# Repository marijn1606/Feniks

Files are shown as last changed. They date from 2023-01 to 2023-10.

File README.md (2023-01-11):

# Feniks

Relatively cheap wifi enabled 4 channel BBQ thermometer based on a ESP32-C3.

The system is powered by an 18650 li-ion battery, and has integrated battery charge and protection circuitry.

The temperature probe data is displayed on a small I2C OLED screen as well as a webserver hosted on the ESP.

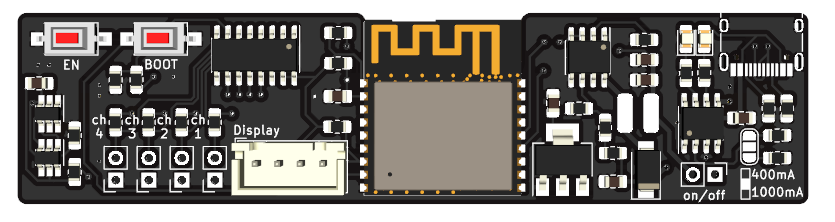
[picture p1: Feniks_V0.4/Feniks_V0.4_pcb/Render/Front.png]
Front

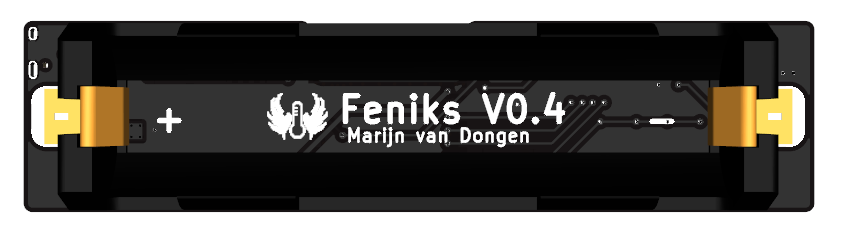
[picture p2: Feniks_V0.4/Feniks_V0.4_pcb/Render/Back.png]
Back


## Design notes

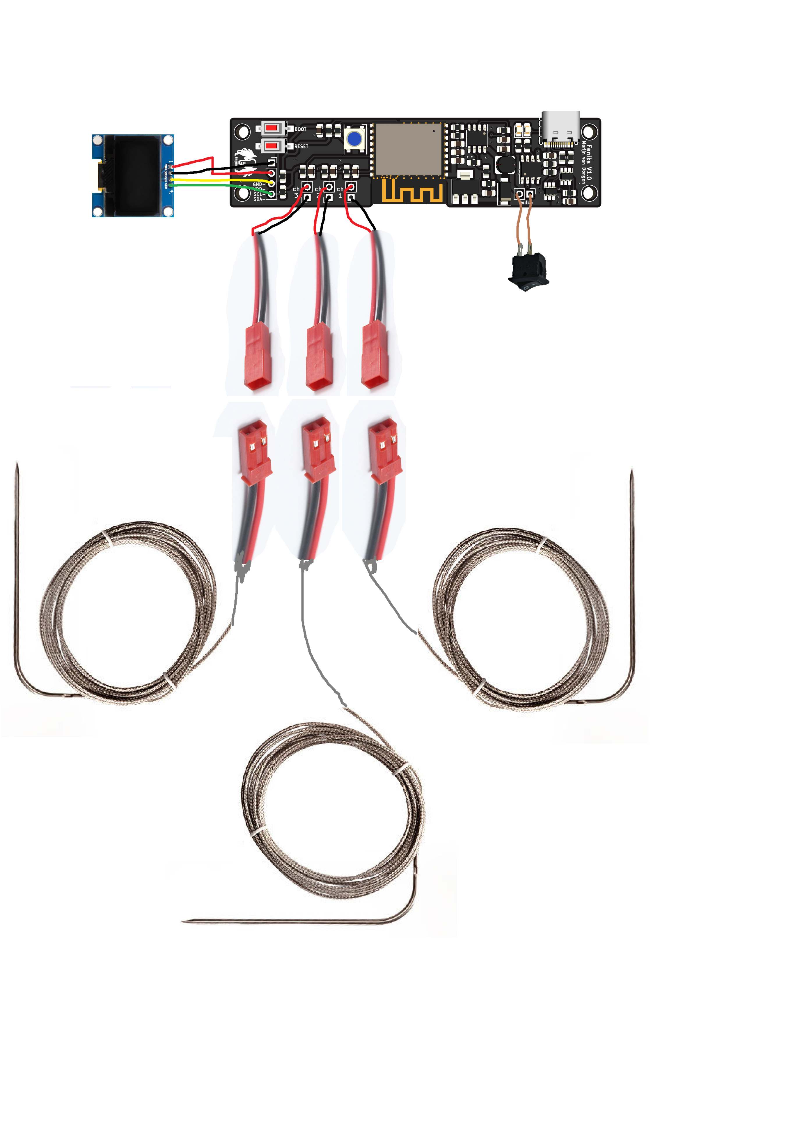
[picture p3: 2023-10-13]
Feniks_V0.5/Feniks_V0.5_pcb/Render/cable_sketch.png

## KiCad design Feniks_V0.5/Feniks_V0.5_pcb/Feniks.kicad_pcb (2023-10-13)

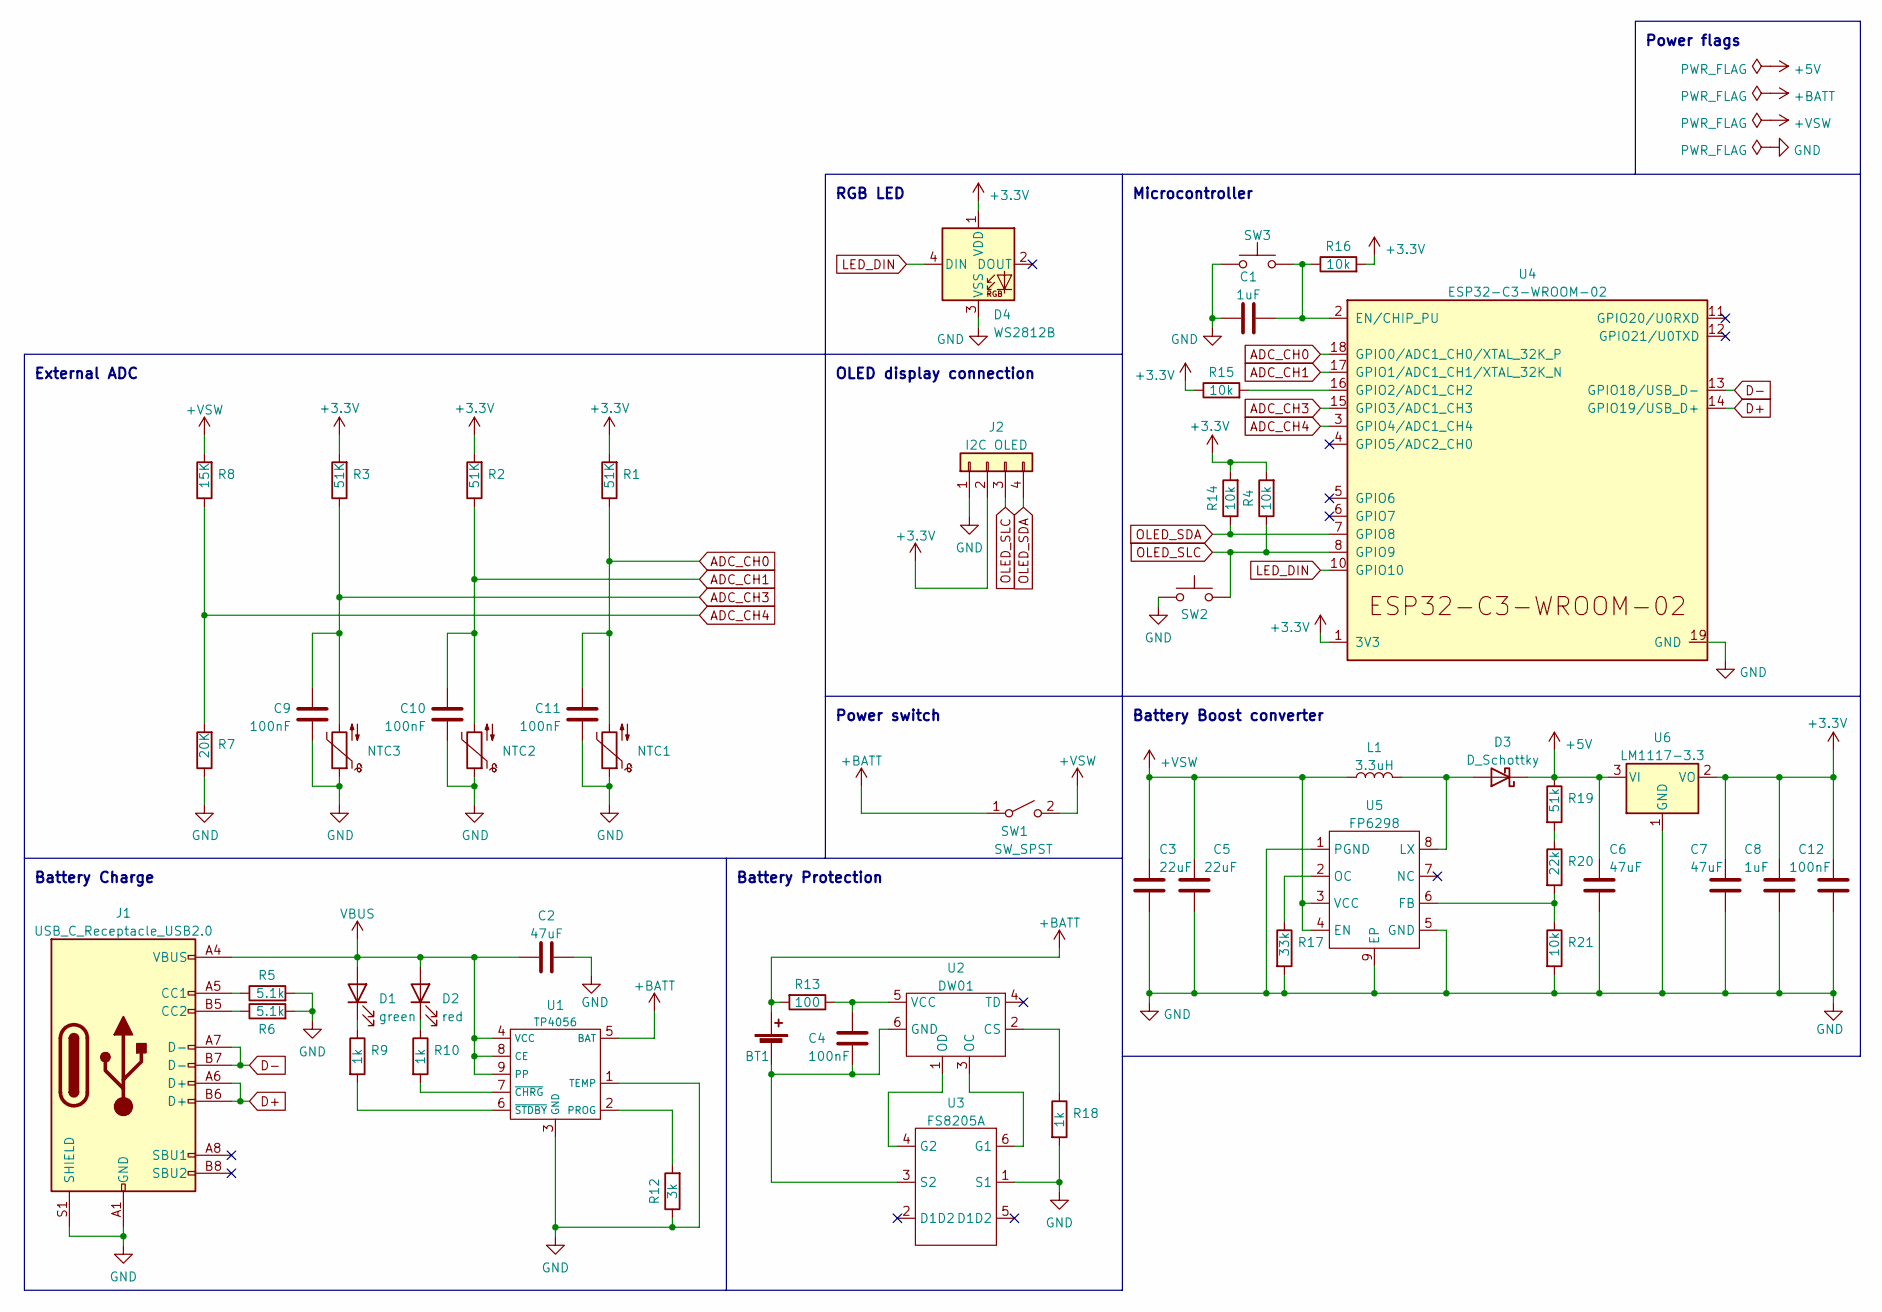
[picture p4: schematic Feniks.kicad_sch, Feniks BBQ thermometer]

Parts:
BT1: Battery_Cell; 18650SMT holder
C1, C8: 1uF; C_0805_2012Metric_Pad1.18x1.45mm_HandSolder
C2, C6, C7: 47uF; C_0805_2012Metric_Pad1.18x1.45mm_HandSolder
C3, C5: 22uF; C_0805_2012Metric_Pad1.18x1.45mm_HandSolder
C4, C9, C10, C11, C12: 100nF; C_0805_2012Metric_Pad1.18x1.45mm_HandSolder
D1: green; LED_0805_2012Metric_Pad1.15x1.40mm_HandSolder
D2: red; LED_0805_2012Metric_Pad1.15x1.40mm_HandSolder
D3: D_Schottky; D_SMA
D4: WS2812B; LED_WS2812B_PLCC4_5.0x5.0mm_P3.2mm
J1: USB_C_Receptacle_USB2.0; USB_C_Receptacle_HRO_TYPE-C-31-M-12
J2: I2C OLED; PinSocket_1x04_P2.54mm_Vertical
L1: 3.3uH; CD43
NTC1, NTC2, NTC3: Thermistor_NTC; PinSocket_1x02_P2.54mm_Vertical
R1, R2, R3: 51K; R_0805_2012Metric_Pad1.20x1.40mm_HandSolder
R4, R14, R15, R16, R21: 10k; R_0805_2012Metric_Pad1.20x1.40mm_HandSolder
R5, R6: 5.1k; R_0805_2012Metric_Pad1.20x1.40mm_HandSolder
R7: 20K; R_0805_2012Metric_Pad1.20x1.40mm_HandSolder
R8: 15K; R_0805_2012Metric_Pad1.20x1.40mm_HandSolder
R9, R10, R18: 1k; R_0805_2012Metric_Pad1.20x1.40mm_HandSolder
R12: 3k; R_0805_2012Metric_Pad1.20x1.40mm_HandSolder
R13: 100; R_0805_2012Metric_Pad1.20x1.40mm_HandSolder
R17: 33k; R_0805_2012Metric_Pad1.20x1.40mm_HandSolder
R19: 51k; R_0805_2012Metric_Pad1.20x1.40mm_HandSolder
R20: 22k; R_0805_2012Metric_Pad1.20x1.40mm_HandSolder
SW1: SW_SPST; PinHeader_1x02_P2.54mm_Vertical
SW2, SW3: SW_Push; SW_SPST_CK_RS282G05A3
U1: TP4056; SOIC-8-1EP_3.9x4.9mm_P1.27mm_EP2.29x3mm_ThermalVias
U2: DW01; SOT-23-6_Handsoldering
U3: FS8205A; SOT-23-6_Handsoldering
U4: ESP32-C3-WROOM-02
U5: FP6298; SOIC-8-1EP_3.9x4.9mm_P1.27mm_EP2.29x3mm_ThermalVias
U6: LM1117-3.3; SOT-223-3_TabPin2

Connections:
+3.3V: C7.1, C8.1, C12.1, D4.1 (VDD), J2.2, R1.2, R2.2, R3.2, R4.2, R14.2, R15.1, R16.2, U4.1 (3V3), U6.2 (VO)
+5V: C6.1, D3.1 (K), R19.1, U6.3 (VI)
+BATT: BT1.1 (+), R13.2, SW1.1 (A), U1.5 (BAT)
+VSW: C3.1, C5.1, L1.1, R8.2, SW1.2 (B), U5.3 (VCC), U5.4 (EN)
ADC_CH0: C11.2, NTC1.2, R1.1, U4.18 (GPIO0/ADC1_CH0/XTAL_32K_P)
ADC_CH1: C10.2, NTC2.2, R2.1, U4.17 (GPIO1/ADC1_CH1/XTAL_32K_N)
ADC_CH3: C9.2, NTC3.2, R3.1, U4.15 (GPIO3/ADC1_CH3)
ADC_CH4: R7.2, R8.1, U4.3 (GPIO4/ADC1_CH4)
D+: J1.A6 (D+), J1.B6 (D+), U4.14 (GPIO19/USB_D+)
D-: J1.A7 (D-), J1.B7 (D-), U4.13 (GPIO18/USB_D-)
GND: C1.1, C2.2, C3.2, C5.2, C6.2, C7.2, C8.2, C9.1, C10.1, C11.1, C12.2, D4.3 (VSS), J1.A1 (GND), J1.A12 (GND), J1.B1 (GND), J1.B12 (GND), J1.S1 (SHIELD), J2.1, NTC1.1, NTC2.1, NTC3.1, R5.2, R6.2, R7.1, R12.1, R17.2, R18.2, R21.2, SW2.1, SW3.1, U1.1 (TEMP), U1.3 (GND), U3.1 (S1), U4.9 (GND), U4.19 (GND), U5.1 (PGND), U5.5 (GND), U5.9 (EP), U6.1 (GND)
LED_DIN: D4.4 (DIN), U4.10 (GPIO10)
unnamed: BT1.2 (-), C4.1, U2.6 (GND), U3.3 (S2)
unnamed: C1.2, R16.1, SW3.2, U4.2 (EN/CHIP_PU)
unnamed: C4.2, R13.1, U2.5 (VCC)
unnamed: D1.1 (K), R9.1
unnamed: D2.1 (K), R10.1
unnamed: D3.2 (A), L1.2, U5.8 (LX)
unnamed: J1.A5 (CC1), R5.1
unnamed: J1.B5 (CC2), R6.1
unnamed: R9.2, U1.6 (~STDBY)
unnamed: R10.2, U1.7 (~CHRG)
unnamed: R12.2, U1.2 (PROG)
unnamed: R15.2, U4.16 (GPIO2/ADC1_CH2)
unnamed: R17.1, U5.2 (OC)
unnamed: R18.1, U2.2 (CS)
unnamed: R19.2, R20.1
unnamed: R20.2, R21.1, U5.6 (FB)
unnamed: U2.1 (OD), U3.4 (G2)
unnamed: U2.3 (OC), U3.6 (G1)
OLED_SDA: J2.4, R14.1, U4.7 (GPIO8)
OLED_SLC: J2.3, R4.1, SW2.2, U4.8 (GPIO9)
VBUS: C2.1, D1.2 (A), D2.2 (A), J1.A4 (VBUS), J1.A9 (VBUS), J1.B4 (VBUS), J1.B9 (VBUS), U1.4 (VCC), U1.8 (CE), U1.9 (PP)

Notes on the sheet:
Microcontroller
Power flags
Battery Protection
Battery Boost converter
OLED display connection
RGB LED
Battery Charge
External ADC
Power switch

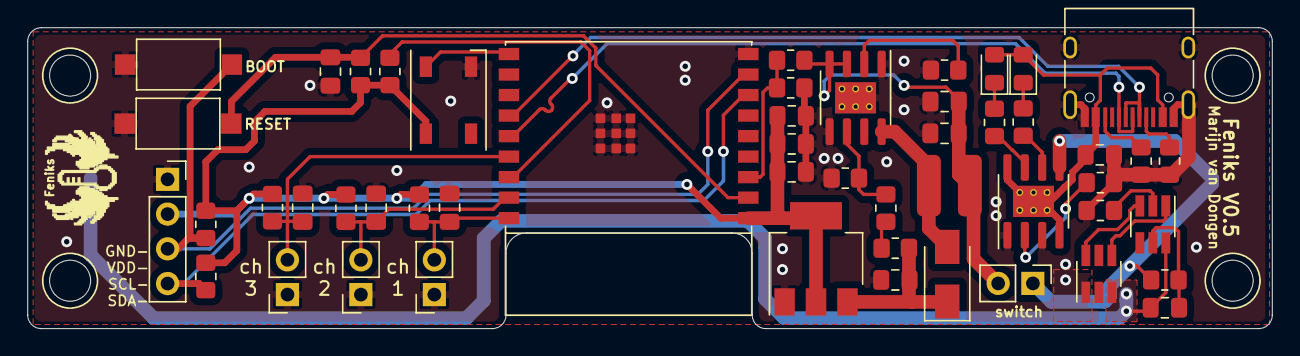
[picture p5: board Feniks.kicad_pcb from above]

Board: 2 copper layers, 91.0 x 22.0 mm, 52 parts (1 on the bottom side), 33 nets.

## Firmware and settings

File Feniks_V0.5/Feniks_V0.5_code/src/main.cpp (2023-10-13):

#include <Arduino.h>
#include <analog.h>
#include <oled.h>
#include <rgb_led.h>
#include <web_interface.h>

#define loop_interval 250
int loop_counter = 0;
double meat;
double ambient;
int battery;
int RSSI;
int hue = 0;

long last_loop_time = 0;

void setup() {
    String ssid;
    Serial.begin(115200);
    oled_setup();
    delay(100);
    neopixelWrite(10, 0, 0, 0);

    while (millis() < 2000) {
        if (digitalRead(GPIO_NUM_9) == LOW) {
            display_wifi_setup("bbq_setup");
            ssid = setup_wifi_network();
        }
    }

    display_connecting_wifi();
    ssid = server_setup();
    display_connected_network(ssid);

    delay(2000);
    meat = get_temp(NTC_CH1);
    ambient = get_temp(NTC_CH2);
    battery = get_battery_level();
}

void loop() {
    while (millis() - last_loop_time < loop_interval) {
    }
    last_loop_time = millis();
    loop_counter++;

    if ((loop_counter % 40) == 0) {
        battery = get_battery_level();
        loop_counter = 0;
    }

    meat = get_temp(NTC_CH1);
    ambient = get_temp(NTC_CH2);
    RSSI = update_Server_Data(meat, ambient, battery);
    update_oled(meat, ambient, battery, RSSI);

    // ReGuBu
    HSL_led(10, hue, 1, 0.05);
    hue > 360 ? hue = 0 : hue += 2;
}

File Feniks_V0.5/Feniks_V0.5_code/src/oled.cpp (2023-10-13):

/**************************************************************************
 This is an example for our Monochrome OLEDs based on SSD1306 drivers

 Pick one up today in the adafruit shop!
 ------> http://www.adafruit.com/category/63_98

 This example is for a 128x64 pixel display using I2C to communicate
 3 pins are required to interface (two I2C and one reset).

 Adafruit invests time and resources providing this open
 source code, please support Adafruit and open-source
 hardware by purchasing products from Adafruit!

 Written by Limor Fried/Ladyada for Adafruit Industries,
 with contributions from the open source community.
 BSD license, check license.txt for more information
 All text above, and the splash screen below must be
 included in any redistribution.
 **************************************************************************/

#include <Adafruit_GFX.h>
#include <Adafruit_SSD1306.h>
#include <Fonts/FreeMonoBold12pt7b.h>
#include <SPI.h>
#include <Wire.h>

#define SCREEN_WIDTH 128  // OLED display width, in pixels
#define SCREEN_HEIGHT 64  // OLED display height, in pixels

#define OLED_RESET -1        // Reset pin # (or -1 if sharing Arduino reset pin)
#define SCREEN_ADDRESS 0x3C  ///< See datasheet for Address; 0x3D for 128x64, 0x3C for 128x32

Adafruit_SSD1306 display(SCREEN_WIDTH, SCREEN_HEIGHT, &Wire, OLED_RESET);

void display_wifi_setup(String SSID) {
    display.clearDisplay();
    display.setCursor(0, 0);
    display.setTextSize(1);
    display.setTextColor(SSD1306_WHITE);
    display.println("Connect phone");
    display.print("to: ");
    display.println(SSID);
    display.println("for setup");
    display.display();
}

void display_connecting_wifi() {
    display.clearDisplay();
    display.setCursor(0, 0);
    display.setTextSize(1);
    display.setTextColor(SSD1306_WHITE);
    display.println("Connecting to WiFi...");
    display.display();
}

void display_connected_network(String SSID) {
    display.clearDisplay();
    display.setCursor(0, 0);
    display.setTextSize(1);
    display.setTextColor(SSD1306_WHITE);
    display.println("Connected:");
    display.print(SSID);
    display.display();
}

void update_oled(double Ch1, double Ch2, int battery, int RSSI) {
    display.clearDisplay();
    display.setFont();
    display.setCursor(85, 4);
    display.setTextSize(1);
    display.setTextColor(SSD1306_WHITE);

    display.print(RSSI);
    display.print("dB");
    if (RSSI > -55) {
        display.drawCircleHelper(117, 11, 10, 2, SSD1306_WHITE);
    }
    if (RSSI > -76) {
        display.drawCircleHelper(117, 11, 7, 2, SSD1306_WHITE);
    }
    if (RSSI > -90) {
        display.drawCircleHelper(117, 11, 4, 2, SSD1306_WHITE);
    }
    if (RSSI == 0) {
        display.drawLine(116, 12, 128, 0, SSD1306_WHITE);
        display.drawLine(128, 12, 116, 0, SSD1306_WHITE);
    }
    display.drawCircle(117, 11, 1, SSD1306_WHITE);

    display.drawRect(2, 4, 15, 8, SSD1306_WHITE);
    display.drawRect(17, 6, 2, 4, SSD1306_WHITE);
    if (battery > 0) {
        display.fillRect(4, 6, 2, 4, SSD1306_WHITE);
    }
    if (battery > 25) {
        display.fillRect(7, 6, 2, 4, SSD1306_WHITE);
    }
    if (battery > 50) {
        display.fillRect(10, 6, 2, 4, SSD1306_WHITE);
    }
    if (battery > 75) {
        display.fillRect(13, 6, 2, 4, SSD1306_WHITE);
    }
    display.drawFastHLine(0, 16, 128, SSD1306_WHITE);
    display.drawFastHLine(0, 40, 128, SSD1306_WHITE);
    display.drawFastHLine(0, 63, 128, SSD1306_WHITE);

    display.setFont(&FreeMonoBold12pt7b);
    display.setCursor(0, 35);
    display.setTextSize(1);

    display.print(F("CH1: "));
    if (Ch1 >= 100) {
        display.println(Ch1, 0);
    } else {
        display.println(Ch1, 1);
    }

    display.print(F("CH2: "));
    if (Ch2 >= 100) {
        display.println(Ch2, 0);
    } else {
        display.println(Ch2, 1);
    }

    display.display();
}

bool oled_setup() {
    // SSD1306_SWITCHCAPVCC = generate display voltage from 3.3V internally
    if (!display.begin(SSD1306_SWITCHCAPVCC, SCREEN_ADDRESS)) {
        return false;
    }
    display.clearDisplay();
    display.fillCircle(64, 32, 16, 1);
    display.setFont();
    display.display();
    return true;
}

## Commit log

2023-01-11 Fresh start
    [Feniks.kicad_pcb, Feniks.kicad_sch]
2023-10-13 clean up
    [BOM.csv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]
